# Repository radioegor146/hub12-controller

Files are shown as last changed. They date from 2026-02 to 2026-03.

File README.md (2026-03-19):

# hub12-controller

Simple HUB12 LED matrices USB controller using RP2040
Currently it is ready to use for 224x192 (7x12) 32x16 monochrome (red) matrices 
It uses:
- PIO to control 12 simultaneous SPI lanes
- DMA to push data to PIO
- Low-level USB w/o any libraries to push data to buffer

It achieves:
- ~160 FPS on 224x192 monochrome display with 12 parallel lanes

Pins are set in [this file](src/hub12.h)

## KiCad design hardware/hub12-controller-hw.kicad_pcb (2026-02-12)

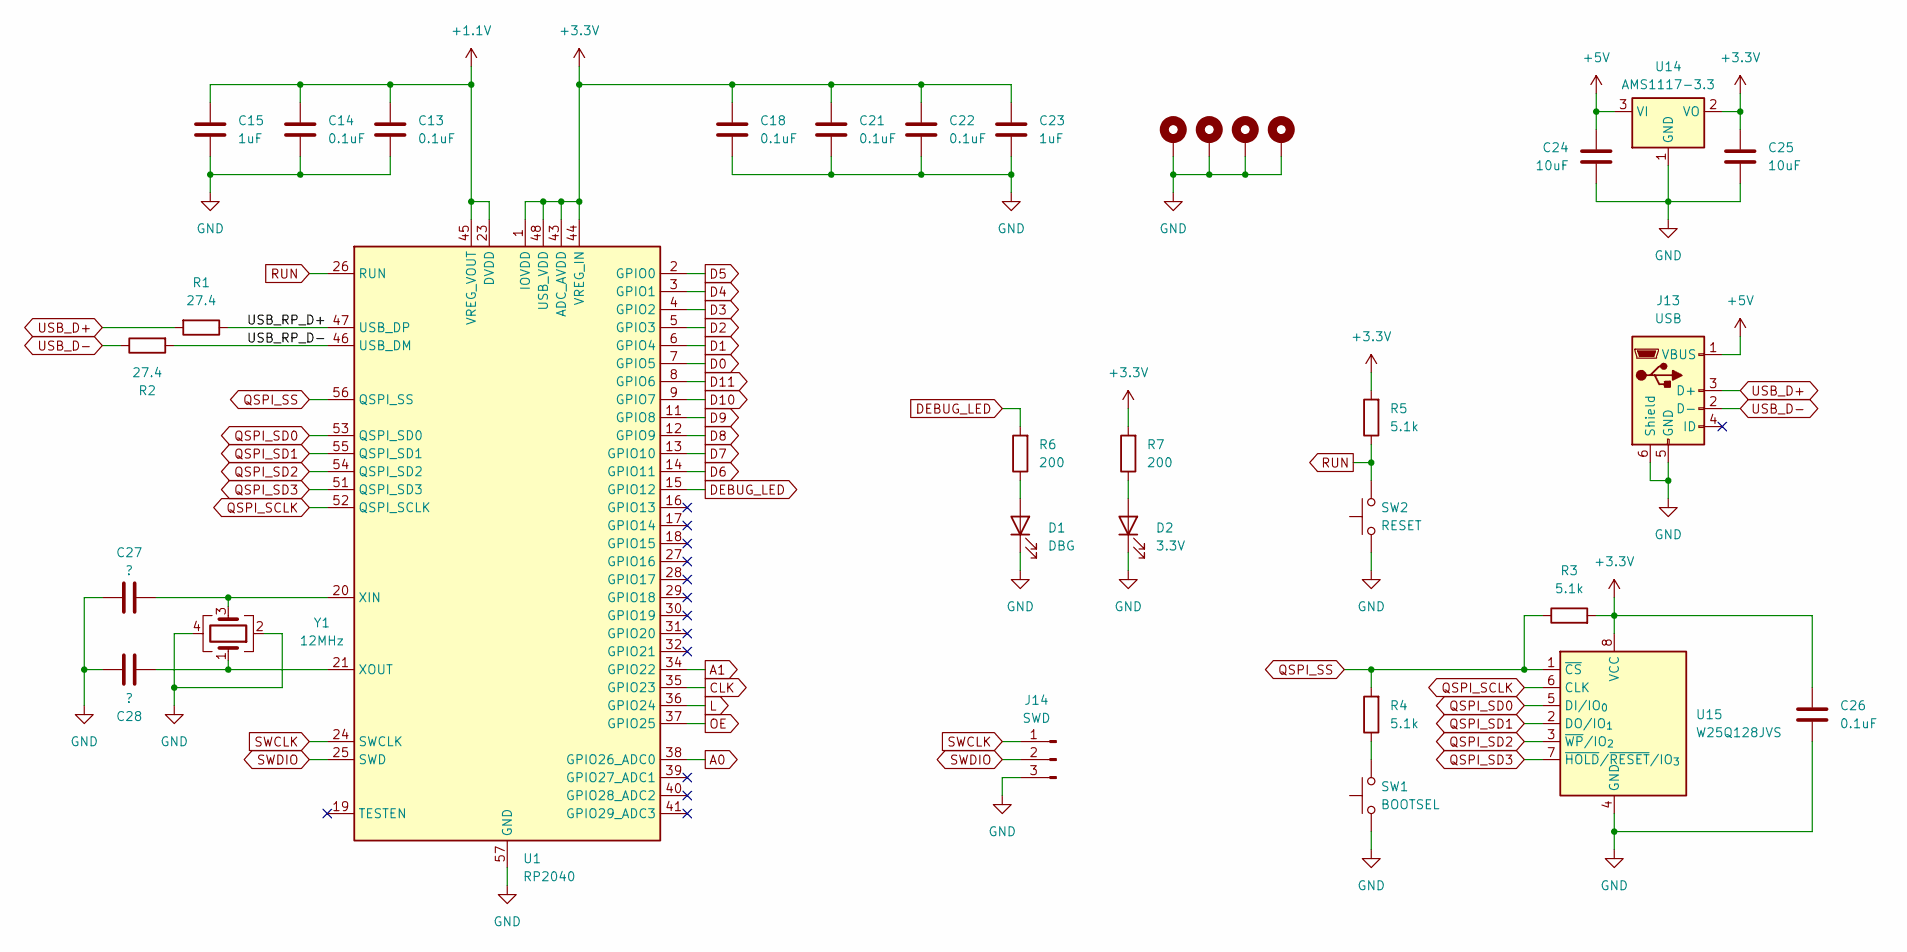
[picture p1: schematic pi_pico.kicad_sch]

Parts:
C13, C14, C18, C21, C22, C26: 0.1uF; C_0805_2012Metric
C15, C23: 1uF; C_0805_2012Metric
C24, C25: 10uF; C_0805_2012Metric
C27, C28: ?; C_0805_2012Metric
D1: DBG; LED_0805_2012Metric
D2: 3.3V; LED_0805_2012Metric
H1, H2, H3, H4: MountingHole_3.2mm_M3_DIN965_Pad_TopBottom
J13: USB; USB_Mini-B_Wuerth_65100516121_Horizontal
J14: SWD; PinHeader_1x03_P2.54mm_Vertical
R1, R2: 27.4; R_0805_2012Metric
R3, R4, R5: 5.1k; R_0805_2012Metric
R6, R7: 200; R_0805_2012Metric
SW1: BOOTSEL; SW_Push_SPST_NO_Alps_SKRK
SW2: RESET; SW_Push_SPST_NO_Alps_SKRK
U1: RP2040; QFN-56-1EP_7x7mm_P0.4mm_EP3.2x3.2mm
U14: AMS1117-3.3; SOT-223-3_TabPin2
U15: W25Q128JVS; SOIC-8_5.3x5.3mm_P1.27mm
Y1: 12MHz; Crystal_SMD_3225-4Pin_3.2x2.5mm_HandSoldering

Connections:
+1.1V: C13.1, C14.1, C15.1, U1.23 (DVDD), U1.45 (VREG_VOUT), U1.50 (DVDD)
+3.3V: C18.1, C21.1, C22.1, C23.1, C25.1, C26.1, R3.2, R5.2, R7.2, U1.1 (IOVDD), U1.10 (IOVDD), U1.22 (IOVDD), U1.33 (IOVDD), U1.42 (IOVDD), U1.43 (ADC_AVDD), U1.44 (VREG_IN), U1.48 (USB_VDD), U1.49 (IOVDD), U14.2 (VO), U15.8 (VCC); also elsewhere on the board
+5V: C24.1, J13.1 (VBUS), U14.3 (VI); also elsewhere on the board
/Pi Pico/USB_RP_D+: R1.1, U1.47 (USB_DP)
/Pi Pico/USB_RP_D-: R2.2, U1.46 (USB_DM)
A0: U1.38 (GPIO26_ADC0); also elsewhere on the board
A1: U1.34 (GPIO22); also elsewhere on the board
CLK: U1.35 (GPIO23); also elsewhere on the board
D0: U1.7 (GPIO5); also elsewhere on the board
D1: U1.6 (GPIO4); also elsewhere on the board
D2: U1.5 (GPIO3); also elsewhere on the board
D3: U1.4 (GPIO2); also elsewhere on the board
D4: U1.3 (GPIO1); also elsewhere on the board
D5: U1.2 (GPIO0); also elsewhere on the board
D6: U1.14 (GPIO11); also elsewhere on the board
D7: U1.13 (GPIO10); also elsewhere on the board
D8: U1.12 (GPIO9); also elsewhere on the board
D9: U1.11 (GPIO8); also elsewhere on the board
D10: U1.9 (GPIO7); also elsewhere on the board
D11: U1.8 (GPIO6); also elsewhere on the board
DEBUG_LED: R6.2, U1.15 (GPIO12)
GND: C13.2, C14.2, C15.2, C18.2, C21.2, C22.2, C23.2, C24.2, C25.2, C26.2, C27.1, C28.2, D1.1 (K), D2.1 (K), H1.1, H2.1, H3.1, H4.1, J13.5 (GND), J13.6 (Shield), J14.3, SW1.1, SW2.1, U1.57 (GND), U14.1 (GND), U15.4 (GND), Y1.2, Y1.4; also elsewhere on the board
L: U1.36 (GPIO24); also elsewhere on the board
unnamed: D1.2 (A), R6.1
unnamed: D2.2 (A), R7.1
unnamed: R4.1, SW1.2
unnamed: C27.2, U1.20 (XIN), Y1.3
unnamed: C28.1, U1.21 (XOUT), Y1.1
OE: U1.37 (GPIO25); also elsewhere on the board
QSPI_SCLK: U1.52 (QSPI_SCLK), U15.6 (CLK)
QSPI_SD0: U1.53 (QSPI_SD0), U15.5 (DI/IO_{0})
QSPI_SD1: U1.55 (QSPI_SD1), U15.2 (DO/IO_{1})
QSPI_SD2: U1.54 (QSPI_SD2), U15.3 (~WP/IO_{2})
QSPI_SD3: U1.51 (QSPI_SD3), U15.7 (~HOLD/~RESET/IO_{3})
QSPI_SS: R3.1, R4.2, U1.56 (QSPI_SS), U15.1 (~CS)
RUN: R5.1, SW2.2, U1.26 (RUN)
SWCLK: J14.1, U1.24 (SWCLK)
SWDIO: J14.2, U1.25 (SWD)
USB_D+: J13.3 (D+), R1.2
USB_D-: J13.2 (D-), R2.1

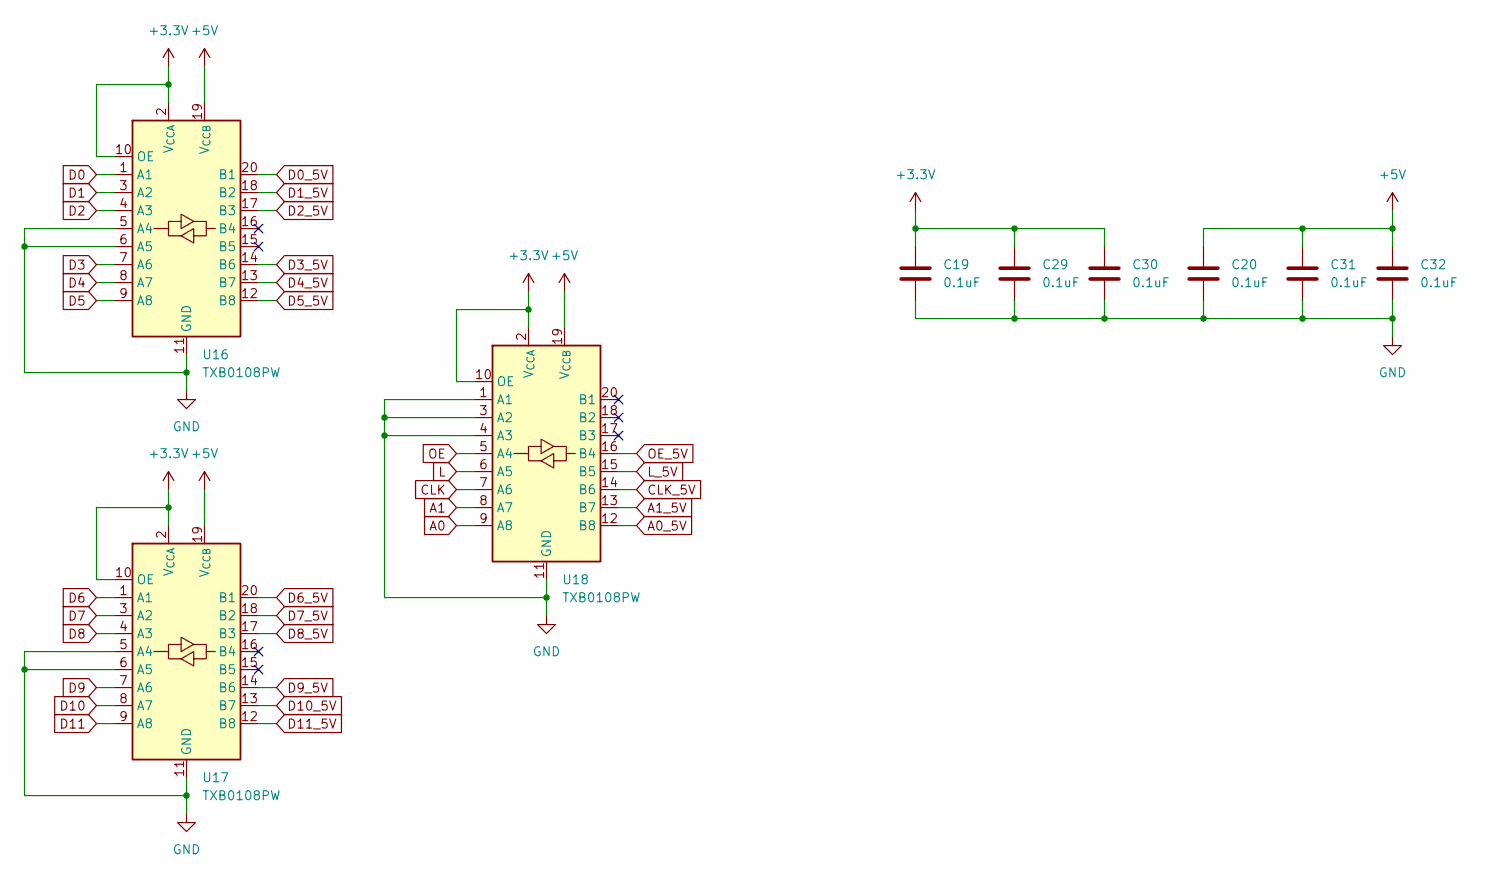
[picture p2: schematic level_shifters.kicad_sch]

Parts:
C19, C20, C29, C30, C31, C32: 0.1uF; C_0805_2012Metric
U16, U17, U18: TXB0108PW; TSSOP-20_4.4x6.5mm_P0.65mm

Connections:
+3.3V: C19.1, C29.1, C30.1, U16.2 (V_{CCA}), U16.10 (OE), U17.2 (V_{CCA}), U17.10 (OE), U18.2 (V_{CCA}), U18.10 (OE); also elsewhere on the board
+5V: C20.1, C31.1, C32.1, U16.19 (V_{CCB}), U17.19 (V_{CCB}), U18.19 (V_{CCB}); also elsewhere on the board
A0: U18.9 (A8); also elsewhere on the board
A0_5V: U18.12 (B8); also elsewhere on the board
A1: U18.8 (A7); also elsewhere on the board
A1_5V: U18.13 (B7); also elsewhere on the board
CLK: U18.7 (A6); also elsewhere on the board
CLK_5V: U18.14 (B6); also elsewhere on the board
D0: U16.1 (A1); also elsewhere on the board
D0_5V: U16.20 (B1); also elsewhere on the board
D1: U16.3 (A2); also elsewhere on the board
D1_5V: U16.18 (B2); also elsewhere on the board
D2: U16.4 (A3); also elsewhere on the board
D2_5V: U16.17 (B3); also elsewhere on the board
D3: U16.7 (A6); also elsewhere on the board
D3_5V: U16.14 (B6); also elsewhere on the board
D4: U16.8 (A7); also elsewhere on the board
D4_5V: U16.13 (B7); also elsewhere on the board
D5: U16.9 (A8); also elsewhere on the board
D5_5V: U16.12 (B8); also elsewhere on the board
D6: U17.1 (A1); also elsewhere on the board
D6_5V: U17.20 (B1); also elsewhere on the board
D7: U17.3 (A2); also elsewhere on the board
D7_5V: U17.18 (B2); also elsewhere on the board
D8: U17.4 (A3); also elsewhere on the board
D8_5V: U17.17 (B3); also elsewhere on the board
D9: U17.7 (A6); also elsewhere on the board
D9_5V: U17.14 (B6); also elsewhere on the board
D10: U17.8 (A7); also elsewhere on the board
D10_5V: U17.13 (B7); also elsewhere on the board
D11: U17.9 (A8); also elsewhere on the board
D11_5V: U17.12 (B8); also elsewhere on the board
GND: C19.2, C20.2, C29.2, C30.2, C31.2, C32.2, U16.5 (A4), U16.6 (A5), U16.11 (GND), U17.5 (A4), U17.6 (A5), U17.11 (GND), U18.1 (A1), U18.3 (A2), U18.4 (A3), U18.11 (GND); also elsewhere on the board
L: U18.6 (A5); also elsewhere on the board
L_5V: U18.15 (B5); also elsewhere on the board
OE: U18.5 (A4); also elsewhere on the board
OE_5V: U18.16 (B4); also elsewhere on the board

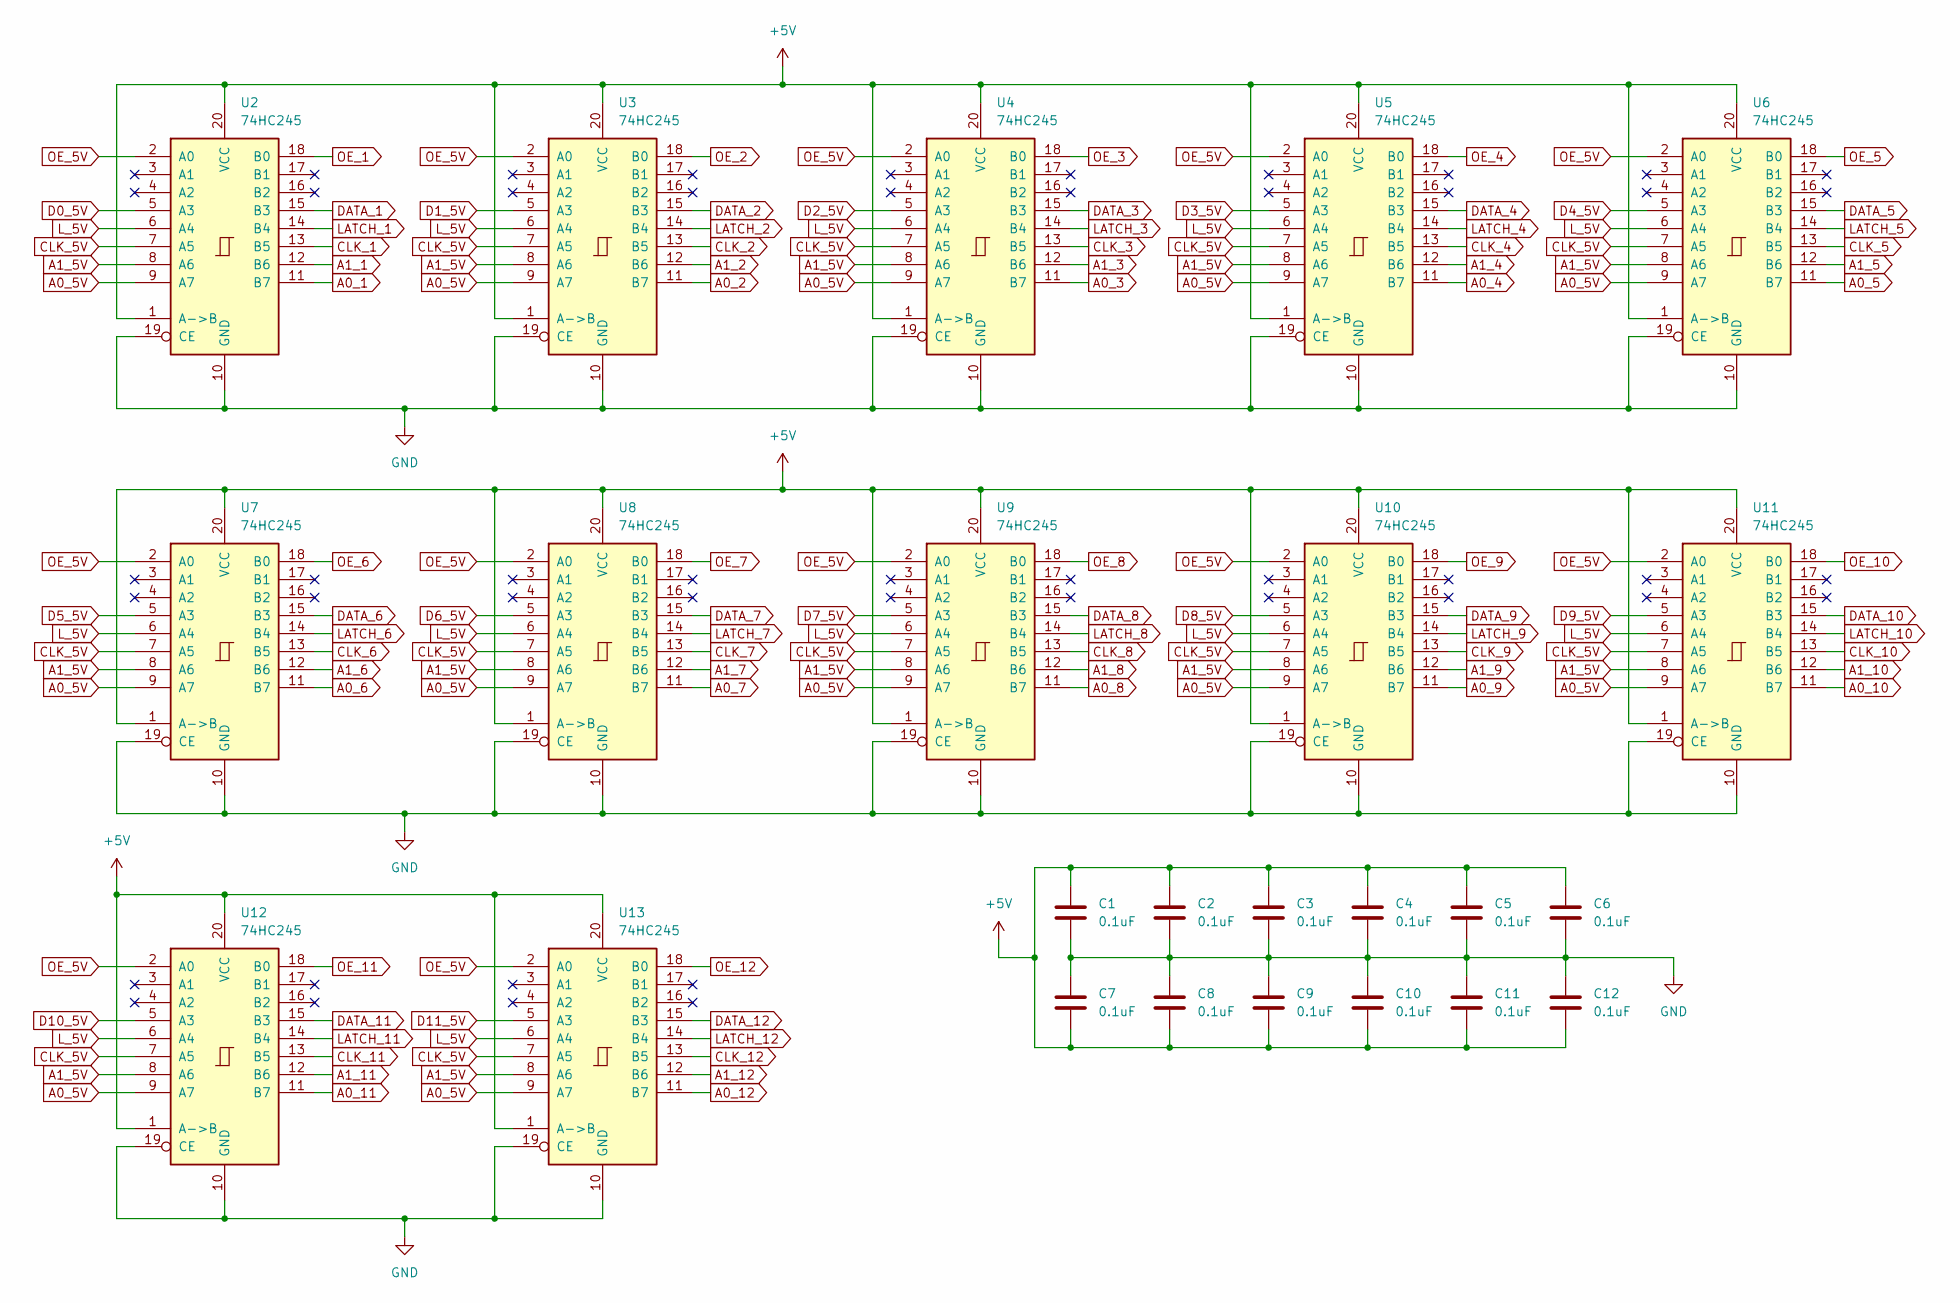
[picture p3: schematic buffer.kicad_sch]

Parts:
C1, C2, C3, C4, C5, C6, C7, C8, C9, C10, C11, C12: 0.1uF; C_0805_2012Metric
U2, U3, U4, U5, U6, U7, U8, U9, U10, U11, U12, U13: 74HC245; TSSOP-20_4.4x6.5mm_P0.65mm

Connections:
+5V: C1.1, C2.1, C3.1, C4.1, C5.1, C6.1, C7.2, C8.2, C9.2, C10.2, C11.2, C12.2, U2.1 (A->B), U2.20 (VCC), U3.1 (A->B), U3.20 (VCC), U4.1 (A->B), U4.20 (VCC), U5.1 (A->B), U5.20 (VCC), U6.1 (A->B), U6.20 (VCC), U7.1 (A->B), U7.20 (VCC), U8.1 (A->B), U8.20 (VCC), U9.1 (A->B), U9.20 (VCC), U10.1 (A->B), U10.20 (VCC), U11.1 (A->B), U11.20 (VCC), U12.1 (A->B), U12.20 (VCC), U13.1 (A->B), U13.20 (VCC); also elsewhere on the board
A0_1: U2.11 (B7); also elsewhere on the board
A0_2: U3.11 (B7); also elsewhere on the board
A0_3: U4.11 (B7); also elsewhere on the board
A0_4: U5.11 (B7); also elsewhere on the board
A0_5: U6.11 (B7); also elsewhere on the board
A0_5V: U2.9 (A7), U3.9 (A7), U4.9 (A7), U5.9 (A7), U6.9 (A7), U7.9 (A7), U8.9 (A7), U9.9 (A7), U10.9 (A7), U11.9 (A7), U12.9 (A7), U13.9 (A7); also elsewhere on the board
A0_6: U7.11 (B7); also elsewhere on the board
A0_7: U8.11 (B7); also elsewhere on the board
A0_8: U9.11 (B7); also elsewhere on the board
A0_9: U10.11 (B7); also elsewhere on the board
A0_10: U11.11 (B7); also elsewhere on the board
A0_11: U12.11 (B7); also elsewhere on the board
A0_12: U13.11 (B7); also elsewhere on the board
A1_1: U2.12 (B6); also elsewhere on the board
A1_2: U3.12 (B6); also elsewhere on the board
A1_3: U4.12 (B6); also elsewhere on the board
A1_4: U5.12 (B6); also elsewhere on the board
A1_5: U6.12 (B6); also elsewhere on the board
A1_5V: U2.8 (A6), U3.8 (A6), U4.8 (A6), U5.8 (A6), U6.8 (A6), U7.8 (A6), U8.8 (A6), U9.8 (A6), U10.8 (A6), U11.8 (A6), U12.8 (A6), U13.8 (A6); also elsewhere on the board
A1_6: U7.12 (B6); also elsewhere on the board
A1_7: U8.12 (B6); also elsewhere on the board
A1_8: U9.12 (B6); also elsewhere on the board
A1_9: U10.12 (B6); also elsewhere on the board
A1_10: U11.12 (B6); also elsewhere on the board
A1_11: U12.12 (B6); also elsewhere on the board
A1_12: U13.12 (B6); also elsewhere on the board
CLK_1: U2.13 (B5); also elsewhere on the board
CLK_2: U3.13 (B5); also elsewhere on the board
CLK_3: U4.13 (B5); also elsewhere on the board
CLK_4: U5.13 (B5); also elsewhere on the board
CLK_5: U6.13 (B5); also elsewhere on the board
CLK_5V: U2.7 (A5), U3.7 (A5), U4.7 (A5), U5.7 (A5), U6.7 (A5), U7.7 (A5), U8.7 (A5), U9.7 (A5), U10.7 (A5), U11.7 (A5), U12.7 (A5), U13.7 (A5); also elsewhere on the board
CLK_6: U7.13 (B5); also elsewhere on the board
CLK_7: U8.13 (B5); also elsewhere on the board
CLK_8: U9.13 (B5); also elsewhere on the board
CLK_9: U10.13 (B5); also elsewhere on the board
CLK_10: U11.13 (B5); also elsewhere on the board
CLK_11: U12.13 (B5); also elsewhere on the board
CLK_12: U13.13 (B5); also elsewhere on the board
D0_5V: U2.5 (A3); also elsewhere on the board
D1_5V: U3.5 (A3); also elsewhere on the board
D2_5V: U4.5 (A3); also elsewhere on the board
D3_5V: U5.5 (A3); also elsewhere on the board
D4_5V: U6.5 (A3); also elsewhere on the board
D5_5V: U7.5 (A3); also elsewhere on the board
D6_5V: U8.5 (A3); also elsewhere on the board
D7_5V: U9.5 (A3); also elsewhere on the board
D8_5V: U10.5 (A3); also elsewhere on the board
D9_5V: U11.5 (A3); also elsewhere on the board
D10_5V: U12.5 (A3); also elsewhere on the board
D11_5V: U13.5 (A3); also elsewhere on the board
DATA_1: U2.15 (B3); also elsewhere on the board
DATA_2: U3.15 (B3); also elsewhere on the board
DATA_3: U4.15 (B3); also elsewhere on the board
DATA_4: U5.15 (B3); also elsewhere on the board
DATA_5: U6.15 (B3); also elsewhere on the board
DATA_6: U7.15 (B3); also elsewhere on the board
DATA_7: U8.15 (B3); also elsewhere on the board
DATA_8: U9.15 (B3); also elsewhere on the board
DATA_9: U10.15 (B3); also elsewhere on the board
DATA_10: U11.15 (B3); also elsewhere on the board
DATA_11: U12.15 (B3); also elsewhere on the board
DATA_12: U13.15 (B3); also elsewhere on the board
GND: C1.2, C2.2, C3.2, C4.2, C5.2, C6.2, C7.1, C8.1, C9.1, C10.1, C11.1, C12.1, U2.10 (GND), U2.19 (CE), U3.10 (GND), U3.19 (CE), U4.10 (GND), U4.19 (CE), U5.10 (GND), U5.19 (CE), U6.10 (GND), U6.19 (CE), U7.10 (GND), U7.19 (CE), U8.10 (GND), U8.19 (CE), U9.10 (GND), U9.19 (CE), U10.10 (GND), U10.19 (CE), U11.10 (GND), U11.19 (CE), U12.10 (GND), U12.19 (CE), U13.10 (GND), U13.19 (CE); also elsewhere on the board
LATCH_1: U2.14 (B4); also elsewhere on the board
LATCH_2: U3.14 (B4); also elsewhere on the board
LATCH_3: U4.14 (B4); also elsewhere on the board
LATCH_4: U5.14 (B4); also elsewhere on the board
LATCH_5: U6.14 (B4); also elsewhere on the board
LATCH_6: U7.14 (B4); also elsewhere on the board
LATCH_7: U8.14 (B4); also elsewhere on the board
LATCH_8: U9.14 (B4); also elsewhere on the board
LATCH_9: U10.14 (B4); also elsewhere on the board
LATCH_10: U11.14 (B4); also elsewhere on the board
LATCH_11: U12.14 (B4); also elsewhere on the board
LATCH_12: U13.14 (B4); also elsewhere on the board
L_5V: U2.6 (A4), U3.6 (A4), U4.6 (A4), U5.6 (A4), U6.6 (A4), U7.6 (A4), U8.6 (A4), U9.6 (A4), U10.6 (A4), U11.6 (A4), U12.6 (A4), U13.6 (A4); also elsewhere on the board
OE_1: U2.18 (B0); also elsewhere on the board
OE_2: U3.18 (B0); also elsewhere on the board
OE_3: U4.18 (B0); also elsewhere on the board
OE_4: U5.18 (B0); also elsewhere on the board
OE_5: U6.18 (B0); also elsewhere on the board
OE_5V: U2.2 (A0), U3.2 (A0), U4.2 (A0), U5.2 (A0), U6.2 (A0), U7.2 (A0), U8.2 (A0), U9.2 (A0), U10.2 (A0), U11.2 (A0), U12.2 (A0), U13.2 (A0); also elsewhere on the board
OE_6: U7.18 (B0); also elsewhere on the board
OE_7: U8.18 (B0); also elsewhere on the board
OE_8: U9.18 (B0); also elsewhere on the board
OE_9: U10.18 (B0); also elsewhere on the board
OE_10: U11.18 (B0); also elsewhere on the board
OE_11: U12.18 (B0); also elsewhere on the board
OE_12: U13.18 (B0); also elsewhere on the board

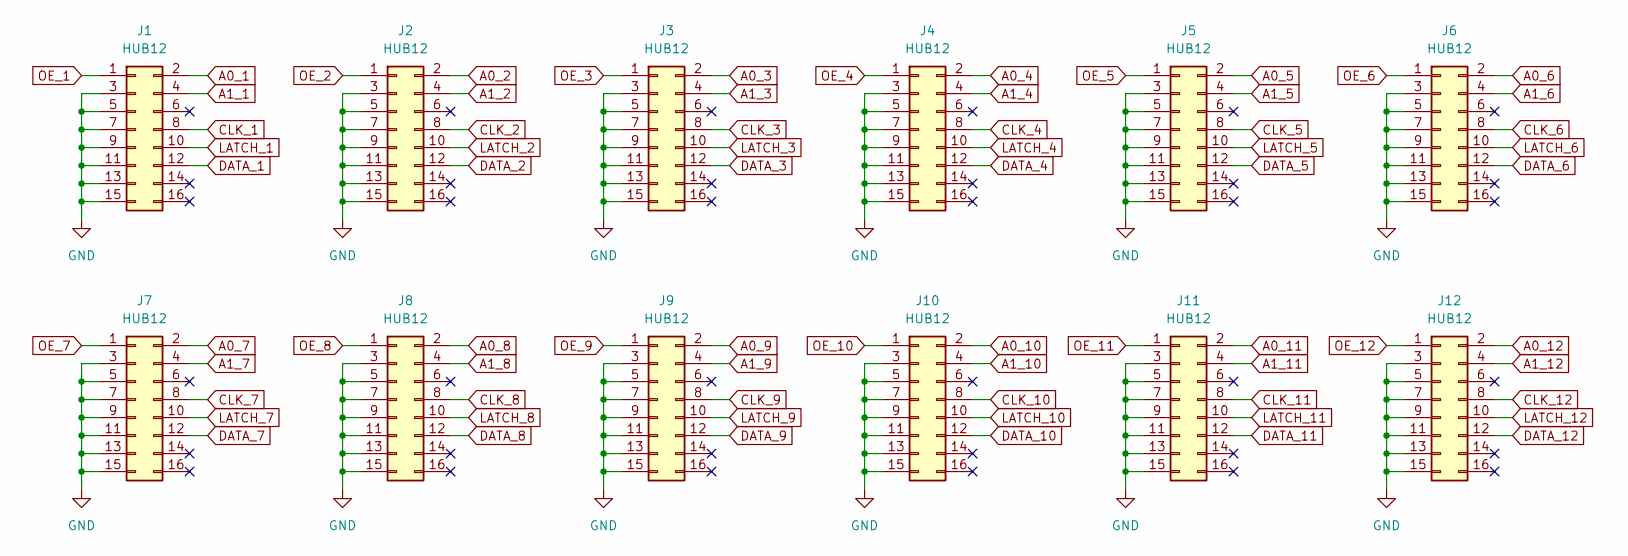
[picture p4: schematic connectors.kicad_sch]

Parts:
J1, J2, J3, J4, J5, J6, J7, J8, J9, J10, J11, J12: HUB12; IDC-Header_2x08_P2.54mm_Vertical

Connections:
A0_1: J1.2; also elsewhere on the board
A0_2: J2.2; also elsewhere on the board
A0_3: J3.2; also elsewhere on the board
A0_4: J4.2; also elsewhere on the board
A0_5: J5.2; also elsewhere on the board
A0_6: J6.2; also elsewhere on the board
A0_7: J7.2; also elsewhere on the board
A0_8: J8.2; also elsewhere on the board
A0_9: J9.2; also elsewhere on the board
A0_10: J10.2; also elsewhere on the board
A0_11: J11.2; also elsewhere on the board
A0_12: J12.2; also elsewhere on the board
A1_1: J1.4; also elsewhere on the board
A1_2: J2.4; also elsewhere on the board
A1_3: J3.4; also elsewhere on the board
A1_4: J4.4; also elsewhere on the board
A1_5: J5.4; also elsewhere on the board
A1_6: J6.4; also elsewhere on the board
A1_7: J7.4; also elsewhere on the board
A1_8: J8.4; also elsewhere on the board
A1_9: J9.4; also elsewhere on the board
A1_10: J10.4; also elsewhere on the board
A1_11: J11.4; also elsewhere on the board
A1_12: J12.4; also elsewhere on the board
CLK_1: J1.8; also elsewhere on the board
CLK_2: J2.8; also elsewhere on the board
CLK_3: J3.8; also elsewhere on the board
CLK_4: J4.8; also elsewhere on the board
CLK_5: J5.8; also elsewhere on the board
CLK_6: J6.8; also elsewhere on the board
CLK_7: J7.8; also elsewhere on the board
CLK_8: J8.8; also elsewhere on the board
CLK_9: J9.8; also elsewhere on the board
CLK_10: J10.8; also elsewhere on the board
CLK_11: J11.8; also elsewhere on the board
CLK_12: J12.8; also elsewhere on the board
DATA_1: J1.12; also elsewhere on the board
DATA_2: J2.12; also elsewhere on the board
DATA_3: J3.12; also elsewhere on the board
DATA_4: J4.12; also elsewhere on the board
DATA_5: J5.12; also elsewhere on the board
DATA_6: J6.12; also elsewhere on the board
DATA_7: J7.12; also elsewhere on the board
DATA_8: J8.12; also elsewhere on the board
DATA_9: J9.12; also elsewhere on the board
DATA_10: J10.12; also elsewhere on the board
DATA_11: J11.12; also elsewhere on the board
DATA_12: J12.12; also elsewhere on the board
GND: J1.3, J1.5, J1.7, J1.9, J1.11, J1.13, J1.15, J2.3, J2.5, J2.7, J2.9, J2.11, J2.13, J2.15, J3.3, J3.5, J3.7, J3.9, J3.11, J3.13, J3.15, J4.3, J4.5, J4.7, J4.9, J4.11, J4.13, J4.15, J5.3, J5.5, J5.7, J5.9, J5.11, J5.13, J5.15, J6.3, J6.5, J6.7, J6.9, J6.11, J6.13, J6.15, J7.3, J7.5, J7.7, J7.9, J7.11, J7.13, J7.15, J8.3, J8.5, J8.7, J8.9, J8.11, J8.13, J8.15, J9.3, J9.5, J9.7, J9.9, J9.11, J9.13, J9.15, J10.3, J10.5, J10.7, J10.9, J10.11, J10.13, J10.15, J11.3, J11.5, J11.7, J11.9, J11.11, J11.13, J11.15, J12.3, J12.5, J12.7, J12.9, J12.11, J12.13, J12.15; also elsewhere on the board
LATCH_1: J1.10; also elsewhere on the board
LATCH_2: J2.10; also elsewhere on the board
LATCH_3: J3.10; also elsewhere on the board
LATCH_4: J4.10; also elsewhere on the board
LATCH_5: J5.10; also elsewhere on the board
LATCH_6: J6.10; also elsewhere on the board
LATCH_7: J7.10; also elsewhere on the board
LATCH_8: J8.10; also elsewhere on the board
LATCH_9: J9.10; also elsewhere on the board
LATCH_10: J10.10; also elsewhere on the board
LATCH_11: J11.10; also elsewhere on the board
LATCH_12: J12.10; also elsewhere on the board
OE_1: J1.1; also elsewhere on the board
OE_2: J2.1; also elsewhere on the board
OE_3: J3.1; also elsewhere on the board
OE_4: J4.1; also elsewhere on the board
OE_5: J5.1; also elsewhere on the board
OE_6: J6.1; also elsewhere on the board
OE_7: J7.1; also elsewhere on the board
OE_8: J8.1; also elsewhere on the board
OE_9: J9.1; also elsewhere on the board
OE_10: J10.1; also elsewhere on the board
OE_11: J11.1; also elsewhere on the board
OE_12: J12.1; also elsewhere on the board

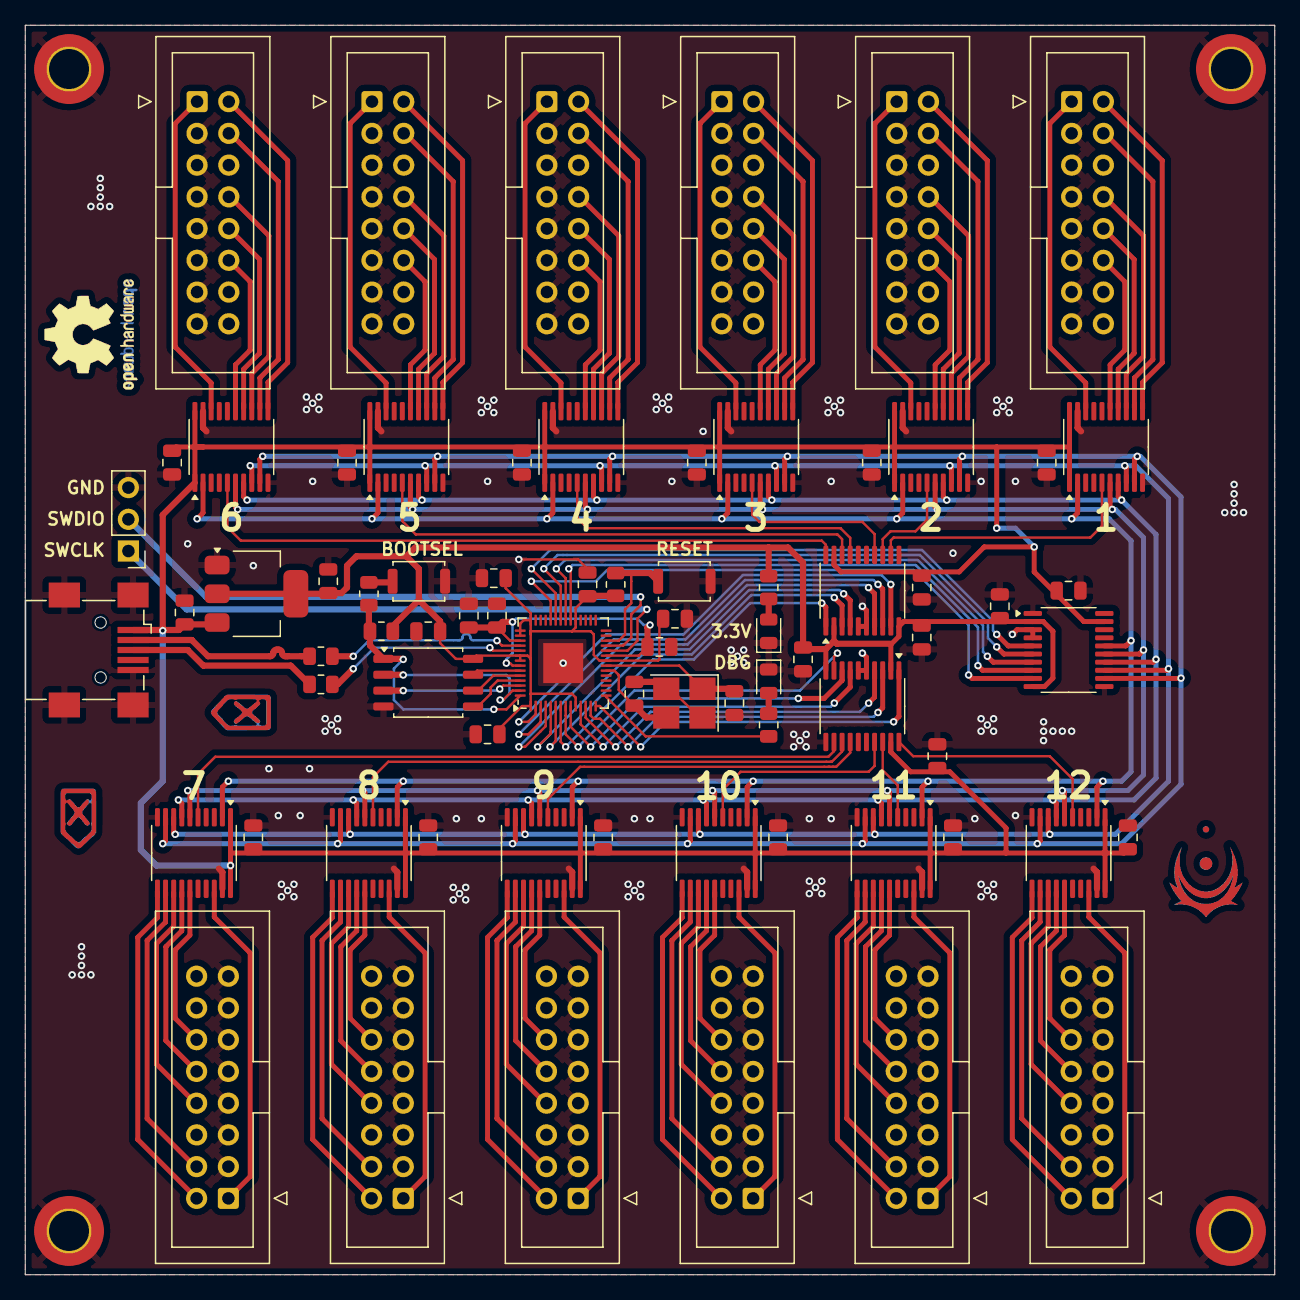
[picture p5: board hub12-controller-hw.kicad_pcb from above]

Board: 2 copper layers, 100.0 x 100.0 mm, 78 parts (0 on the bottom side), 129 nets.

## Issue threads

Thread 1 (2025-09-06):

is it working ? confused at function of tight_loop_contents

Kamal-Sonani, 2025-09-06:
can you please share uf2 as well to quick check & run & is it possible to make it 256 LED in width ?

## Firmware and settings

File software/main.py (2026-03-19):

import usb.core
import usb.util
import time
import random

while True:
    try:
        dev = usb.core.find(idVendor=0xe146, idProduct=0x1337)

        if dev is None:
            raise ValueError('Device not found')

        dev.reset()
        dev.set_configuration()

        cfg = dev.get_active_configuration()
        print(cfg)
        intf = cfg[(0,0)]

        data_out_ep = usb.util.find_descriptor(intf, custom_match = lambda e: e.bEndpointAddress == 0x01)
        reset_out_ep = usb.util.find_descriptor(intf, custom_match = lambda e: e.bEndpointAddress == 0x02)

        reset_out_ep.write([0] * 64)

        start_time = time.time()
        total_bytes = 0

        target_fps = 60

        delay = 0
        i = 0

        while True:
            i += 1
            data = [0xFF] * 5376
            data_out_ep.write(data)
            total_bytes += 5376
            speed = total_bytes / (time.time() - start_time)
            if i % 100 == 0:
                print(f'{speed * 8 / 1000 / 1000:.2f}MB/s, {speed / 5376:.2f} FPS, delay {delay * 1000:.2f} ms')
            fps = speed / 5376
            if fps > target_fps:
                delay = (1 / target_fps - 1 / fps)
            else:
                delay = 0
            # time.sleep(delay)

        # 120 fps = 0.0083 per frame
        # 160 fps = 0.00625 per frame
        # 
    except Exception as e:
        print(e)
        time.sleep(0.5)

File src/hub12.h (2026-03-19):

#ifndef HUB12_H_
#define HUB12_H_

#include <stdbool.h>
#include <stdint.h>

#define WIDTH 224
#define HEIGHT 192

#define DMA_BUFFER_SIZE (WIDTH * HEIGHT / 8 / 3 * 4)

#define MIN_DATA_PIN 0
#define MAX_DATA_PIN 11
#define CLOCK_PIN 23
#define LATCH_PIN 24
#define OUTPUT_ENABLE_PIN 25
#define A0_PIN 26
#define A1_PIN 22

#define USED_PIO pio0
#define USED_SM 0
#define PIO_CLOCK_DIVIDER 8

#define DMA_IRQ_TO_USE 0

#define LATCH_TOGGLE_CYCLES 100
#define PIO_END_WAIT_CYCLES 100

void Hub12Initialize();
uint8_t* Hub12GetAvailableBuffer();
void Hub12PushBuffer();

#endif  // HUB12_H_

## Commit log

2026-02-12 add hardware and software
    [buffer.kicad_sch, connectors.kicad_sch, hub12-controller-hw.kicad_pcb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]
2026-03-18 fix dma buffer size
    [hub12.c, hub12.h, main.py]
